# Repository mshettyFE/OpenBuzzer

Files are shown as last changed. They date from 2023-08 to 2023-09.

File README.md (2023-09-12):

An ESP8266-based quizbowl buzzer system.

# Downloading Code and Setting up Environment

An important note: I developed this on a Windows machine using WSL. I have no reason to believe that this code won't work across platforms, but your mileage may vary.

You first need to download VSCode and get the PlatformIO extension.

VSCode can be downloaded from [here](https://code.visualstudio.com/), while the PlatformIO instructions can be found [here](https://platformio.org/install/ide?install=vscode). The [quick start guide](https://docs.platformio.org/en/latest/integration/ide/vscode.html#quick-start) will give you an idea of the basic functionality of the extension.

You will also need the C/C++ Extension Pack (Can search and install with extension manager )

Once the above development tools are installed, open up a terminal and download the repository with the command

```
git clone https://github.com/mshettyFE/OpenBuzzer.git
```

NOTE: for Windows with WSL, you need to open up a WSL terminal instead of a typical powershell windows terminal.

cd into downloaded repository, then fire up VSCode with ```code .``` and click on the PlatformIO icon on the left hand taskbar. Choose the "Pick a Folder" option and select the root folder of the git repo you just downloaded. Wait for all the configurations to get setup.

# Uploading Code to Units

In general, you need to do the following steps:

1. Copy over a .cpp file in the [scripts](/scripts/) directory into [main.cpp](/src/main.cpp).
2. Plug in the ESP8266 NODEMCU dev board to a USB port
   * Aside: If you are using WSL, you need to passthrough the USB connection from Windows to WSL. See [here](https://learn.microsoft.com/en-us/windows/wsl/connect-usb) for instructions on how to do so.
3. Navigate to the PlatformIO icon in the taskbar, then select "Upload". It should just work.

For client machines (ie. each individual buzzer), copy over [Client.cpp](/scripts/ClientSide/Client.cpp) to main.

## Uploading filesystem (Server only)

For the main control unit (ie. server), you also need to flash the filesystem image prior to uploading the code. Follow steps 1-2 above, then under the PlatformIO tab, select ```Build Filesystem Image```. Afterwards, select ```Upload Filesystem Image```.

Once that is done, you can copy over [Server.cpp](/scripts/ServerSide/Server.cpp) to main and upload like normal.

# Ordering PCBs

The gerber files needed to create the PCBs are located at [here](/design/PCBs/Gerber). These specific design files work for [JLCPCB](https://jlcpcb.com/). Just drag and drop the zip files and order however many you want (Suggested is 5 Server boards and 15 client boards).

If you are ordering from a different manufacturer, or some of your component footprints are egregiously misaligned with the board (the NODEMCU form factor and RJ45 PCB mounts are not particularly well standardized), you can directly modify the design files located [here](/design/PCBs/KiCad/). 

A suggestion to see if the current design works for you PRIOR to ordering from a fabricating service: print out the PCB layout on printer paper and see if your components roughly line up. It's OK if the pins don't line up exactly, since they can be slightly bent with pliers to correctly mate with the drill holes.

# Assembly Tips

* Keep the soldering iron as low as feasible (Try not to go above 350 F). Lower heat means you are less likely to damage components and your tip
* Remember to properly clean the iron before and after use, and re-tin whenever you aren't using the iron
* Be careful not to smear solder onto the PCB traces while soldering. Pain to clean up
* The top left corner of the PCB (ie corner near OLED display) should align with the little divet on the bottom part of the enclosure
* OLED contacts go into indentation in OLED holder
* You can get away with 3 screws to secure the OLED, the PCB, and the cover 
* Make sure that there are no shorts between wires prior to hot gluing them in place (pain to remove)

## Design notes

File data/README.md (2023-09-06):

Here are website files.

* game_index.html: html skeleton
  * Rows get added to Ranking tbody as players buzz in
  * When Rescan gets pressed, Alive tbody gets populated with the current players connected
  * When Clear gets pressed, both Rranking and Alive are cleared, and all buzzers are reset to unlocked
* index.css: Bare bones css file
* Requests.jss: Opens up a WebSocket between client (say, a mobile device) and ESP8266 server. Reads JSON response from server and updates display accordingly. Also plays A4 for 1 second when someone first buzzes in
* A41Sec.mp3: tone that plays when player buzzes in

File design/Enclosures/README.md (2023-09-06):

Contains design files to 3D print enclosures.

* ```Fusion360``` contains .f3d files.
  * ButtonHoleChecker was a test print to see what size hole and threading worked for the buttons
  * OLEDHolder was a test print to pin down the hole placement that works for **MOST** displays. They might not align perfectly, but you should be able to drive in the screws.
  * BuzzerBot is where the PCB gets mounted. It is shared between the client and the server enclosures
  * BuzzerClientTop and BuzzerServerTop cover the PCB and provide access ports

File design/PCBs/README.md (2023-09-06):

PCB design files

* Gerber contains the files that get send to a fab lab. These files are for JLCPCB
* KiCad contains the KiCad projects for both all Clients and Server

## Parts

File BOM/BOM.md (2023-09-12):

# BOM (Bill of Materials)
Cost breakdown of each component and potential sources of each material. Excludes shipping and taxes. No affiliated links.

| Part | Cost | Minimum Count | Link |
| -----| ----- | ----| -----|
| ESP8266 NODEMCU| $0.99 | 2 (1 for server, 1 per client)| https://www.aliexpress.us/item/3256805522032182.html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|
|
| RS485 Modules | $0.30 | (1 for server, 1 per client) | https://www.aliexpress.us/item/3256801435484195.html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| 
| USB-C Breakout Board with Pins| $ 0.17 |  1 for the server | https://www.aliexpress.us/item/3256804935738941.html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|
RJ45 Ethernet PCB Mount | $1.73 per 10 | (1 for server, 1 per client) | https://www.aliexpress.us/item/2251832663908888.html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|
OLED Display | $1.21 | (1 for server, 1 per client) | https://www.aliexpress.us/item/2251832644208699.html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|
7 mm Momentary Push Button, Normally Open (NO) | $3.59 for 10 | (1 for server, 1 per client) | https://www.aliexpress.us/item/2251832768448275.html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 |
M2 x 4mm Self tapping  Phillip Head screws | $0.80 for 100 | In Theory, 12 per unit. You can use 9 though| https://www.aliexpress.us/item/3256804788361012.html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 |
3D Printing filament | For PLA, cheapest is around $20 dollars per kg | Each unit takes around 150 g, so around $3.00 per unit | https://www.amazon.com/XYZprinting-RFPLCXUS0CH-Vinci-Filament-Pearl/dp/B0142FW8W6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 |
22 awg solid core wire | $8.29 for 5 rolls of 40m 22 awg | around 40 cm per unit ($0.05) | https://www.aliexpress.us/item/2251832718635676.html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|
Solder | $1.00 for 50 g | Depends on how good of a soldering job you do | https://www.aliexpress.us/item/3256805017664990.html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|

You will need access to a 3D printer to create the enclosures.

With regards to the PCB, you will need some additional tools:

* a soldering iron
  * Since you will be making a lot of solder joints, get a quality soldering iron (preferably one with electronic temperature control)
* wire strippers
* snips
* electronics pliers
* brass wire sponge: to clean the tip

Some tools that are useful to have (but not strictly necessary):

* Helping hands (the tool. Although having friend hold some wires while you solder also works)
* A hot glue gun: used to cover up exposed leads from stripped wires and prevent shorts
* Solder suction gun: Good for when you screw up a solder joint
* Multimeter: Used to test for inadvertent short between traces

The cost per unit (excluding tax and shipping) comes out to:

* $6.40 for the server
* $6.23 for the client

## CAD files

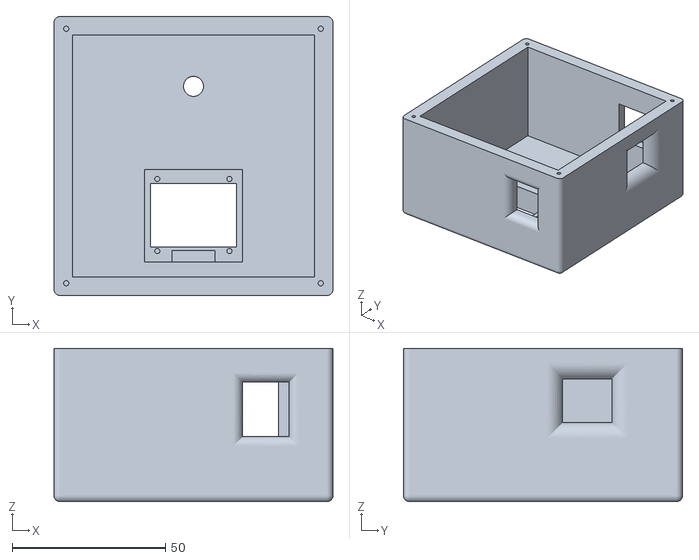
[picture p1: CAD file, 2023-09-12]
design/Enclosures/STL/BuzzerServerTop.stl
90.9 x 90.9 x 50.0

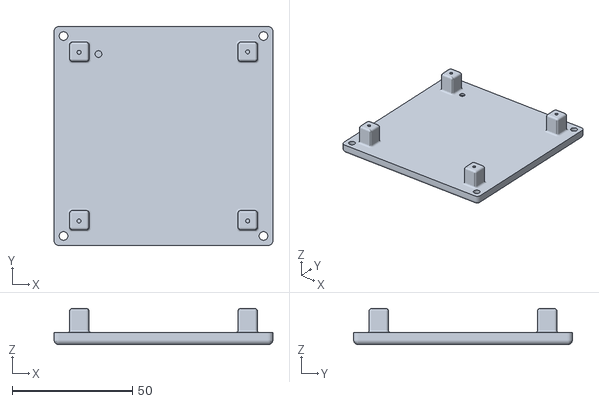
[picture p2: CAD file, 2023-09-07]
design/Enclosures/STL/BuzzerBot.stl
90.9 x 90.9 x 15.0

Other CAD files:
design/Enclosures/STL/BuzzerClientTop.stl
design/Enclosures/Fusion360/ButtonHoleChecker.f3d
design/Enclosures/Fusion360/BuzzerBot.f3d
design/Enclosures/Fusion360/BuzzerClientTop.f3d
design/Enclosures/Fusion360/BuzzerServerTop.f3d
design/Enclosures/Fusion360/OLEDHolder.f3d

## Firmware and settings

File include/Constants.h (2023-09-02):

#ifndef CONSTANTS
#define CONSTANTS

#include <ESP8266WiFi.h>
#include <ESPAsyncTCP.h>
#include <ESPAsyncWebServer.h>
#include <stdint.h>

const bool debug = false;
const bool v_debug = false;

const uint8_t SCREEN_WIDTH  = 128; // OLED display width, in pixels
const uint8_t SCREEN_HEIGHT =  64; // OLED display height, in pixels

// Possible actions to update web interface. WEB_UPDATE only send out by server
// WEB_CLEAR, WEB_RESCAN initiated by client

enum WebpageMessageTypes {WEB_INVALID,WEB_UPDATE,WEB_CLEAR,WEB_RESCAN,WEB_NOTHING};

const IPAddress local_IP(192,168,4,22);
const IPAddress gateway(192,168,4,9);
const IPAddress subnet(255,255,255,0);

// Possible Messages that can be sent. 
// ALIVE is used to register a device.
// TIMING is used to get current buzz-in time of device
// LOCK_IN is used to set a client as buzzed in
// RESET is used to clear state of devices

enum MessageType {INVALID=0,ALIVE=1,TIMING=2,LOCK_IN=3, RESET=4};

enum SenderType {SERVER=1, CLIENT=2};

const int8_t INVALID_DEVICE = 0;
const int8_t ALL_DEVICES = -1;

// ENABLE_PIN to toggle between transmit and receive
const uint8_t ENABLE_PIN = 2;

// TRIGGER_PIN to state if button has been pushed
const uint8_t TRIGGER_PIN = 14;

// I2S DAC pins
const uint8_t LRCLK_PIN= 12;
const uint8_t BCLK_PIN= 13;
const uint8_t DIN_PIN= 0;

// Maximum number of devices that can be connected
const uint8_t MAX_DEVICES = 10;

// Testing response wait time in microseconds.
const uint64_t WAIT_TIME = 100000;
// SendAll wait time in microseconds
const uint64_t SEND_ALL_WAIT_TIME = 500000;
// Webserver client refresh time
const uint64_t refresh_client_pool = 1000000;

// Start and end characters for messages
const char start_marker = '!';
const char end_marker = '@';
// Delimiter to seperate different values within a message
const char delimiter[2] = "#";

// size of buffer for both client and server (messages shouldn't exceed 32 bits)
const uint8_t bufferSize = 32;

typedef struct Record {
	int8_t	device_id;
	uint64_t	timing;
} Rec;

extern WebpageMessageTypes current_webpage_update;

#endif

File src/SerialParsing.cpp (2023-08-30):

#include "SerialParsing.h"
#include "Constants.h"

#include <errno.h>
#include <Arduino.h>
#include <stdint.h>

bool SetInvalidServer(int8_t device_id, MessageType& msgt,uint64_t& timing){
    msgt = INVALID;
    device_id = 0;
    timing = 0;
    return false;
}

bool SetInvalidClient(int8_t device_id, MessageType& msgt){
    msgt = INVALID;
    device_id = 0;
    return false;
}

void ReceiveChar(char* buffer, uint8_t& buffer_index, bool& msg_start,bool& msg_end){
// read in a single character from the bus if available
  char rc;
  while(Serial.available() > 0 ){
    rc = Serial.read();
//    Serial.printf("%c",rc);
    if(!msg_start){
          if(rc==start_marker){
//            Serial.println("start");
            // Point to beginning of array, and allow future reads of Serial to be processed
            buffer_index = 0;
            msg_start = true;
          }
    }
    else{
      if(rc!=end_marker){
// read in characters, then advance index
//            Serial.println("mid");
        buffer[buffer_index] = rc;
        buffer_index++;
// If the index exceeds the buffer size,t then we have gone on for too long. set msg_start and msg_end to false, reset buffer to start and return
        if(buffer_index>=bufferSize){
          msg_start = false;
          msg_end = false;
          buffer_index = 0;
          return;
        }
      }
      else{
// We are at the end of the message. Need to null terminate string
//            Serial.println("end");
        buffer[buffer_index] = '\0';
        msg_end = true;
// exit to start parsing message
        return ;
      }
    }
  }
}

bool ParseMsgServer(char* buffer, int8_t& device_id, MessageType& MSGT, uint64_t& timing){
// Assumes message has one of two forms:
// !%d#%d#%d@ where the first %d is sender_id, second %d is device ID and   third %d is the message type 
// !%d#%d#%d#%llu@ where the first %d is sender_id, second %d is device ID, and  third %d is the message type and %llu is a time

// Check Sender ID
  if(debug){
    Serial.printf("\nClient");
    Serial.println(buffer);
    Serial.printf("\n");
  }
  char* endIndex = strtok(buffer,delimiter);
  if(endIndex==NULL){
    return SetInvalidServer(device_id,MSGT,timing);
  }
  int sender_id = atoi(endIndex);
  if(sender_id!=CLIENT){
    return SetInvalidServer(device_id,MSGT,timing);
  }
// Check Device ID
  endIndex = strtok(NULL,delimiter);
// invalid message rest of message irrelevant
  if(endIndex==NULL){
    return SetInvalidServer(device_id,MSGT,timing);
  }
  device_id = atoi(endIndex);
  if((device_id<1 || device_id>MAX_DEVICES)){
    return SetInvalidServer(device_id,MSGT,timing);
  }
// Parse message type. For ALIVE and TIMING, check for additional timing info
  endIndex = strtok(NULL,delimiter);
// invalid message rest of message irrelevant
  if(endIndex==NULL){
    return SetInvalidServer(device_id,MSGT,timing);
  }
  int temp = atoi(endIndex); 
// invalid message type
  if(temp<ALIVE || temp>RESET){
    return SetInvalidServer(device_id,MSGT,timing);
  }
  else{
    switch(temp){
      case ALIVE:
        MSGT = ALIVE;
        // Grab next part
        endIndex = strtok(NULL, delimiter);
        if(endIndex==NULL){
          return SetInvalidServer(device_id,MSGT,timing);
        }
        timing = strtoul(endIndex,NULL,10);
        if(errno){
          return SetInvalidServer(device_id,MSGT,timing);
        }
        break;
      case TIMING:
        MSGT = TIMING;
        // Grab next part
        endIndex = strtok(NULL, delimiter);
        if(endIndex==NULL){
          return SetInvalidServer(device_id,MSGT,timing);
        }
        timing = strtoul(endIndex,NULL,10);
        if(errno){
          return SetInvalidServer(device_id,MSGT,timing);
        }
        break;
      case LOCK_IN:
          MSGT = LOCK_IN;
          break;
      case RESET:
          MSGT = RESET;
          break;
      case INVALID:
     default:
        return SetInvalidServer(device_id,MSGT,timing);
   }
  }
  return true;
}

bool ParseMsgClient(char* buffer, int8_t& device_id, MessageType& MSGT){
// Assumes message has the following form:
// !%d#%d#%d@ where the first %d is either SERVER or CLIENT, the second %d is the device_id and third %d is message type
  if(debug){
    Serial.printf("\nServer");
    Serial.println(buffer);
    Serial.printf("\n");
  }
// Check if first character is from SERVER
  char* endIndex = strtok(buffer,delimiter);
// If we read nothing, return invalid message
  if(endIndex==NULL){
    return SetInvalidClient(device_id,MSGT);
  }
  int sender_id = atoi(endIndex);
  if(sender_id!=SERVER){
    return false;
  }

// Check device ID
  endIndex = strtok(NULL,delimiter);
// If we read nothing, return invalid message
  if(endIndex==NULL){
    return SetInvalidClient(device_id,MSGT);
  }
// check if device_id is valid
  device_id = atoi(endIndex);
// continue if device_id is all devices
  if(device_id==ALL_DEVICES){
    ;
  }
// Since the device_id is not all devices, this means that the device id should be inclusively bounded between 1 and MAX_DEVICES
  else if( device_id<1 || device_id > MAX_DEVICES){
    return SetInvalidClient(device_id,MSGT);
  }

// Grab next part
  endIndex = strtok(NULL, delimiter);
  if(endIndex==NULL){
    return SetInvalidClient(device_id,MSGT);
  }

// This should be the MessageType. Since the enum is contiguous, we can check if atoi() returns something below or above valid range of enum
  int temp = atoi(endIndex);
// invalid message type
  if(temp<ALIVE || temp>RESET){
    return SetInvalidClient(device_id,MSGT);
  }
  else{
    switch(temp){
      case ALIVE:
        MSGT = ALIVE;
        break;
      case RESET:
        MSGT = RESET;
        break;
      case TIMING:
        MSGT = TIMING;
        break;
      case LOCK_IN:
        MSGT = LOCK_IN;
        break;
      case INVALID:
      default:
        return SetInvalidClient(device_id,MSGT);
    }
  }
  return true;
}

void SendMsgServer(int8_t Device_ID, MessageType msgt){
// turn on transmission
  if(debug){
    Serial.printf("Send:%d,%d\n",Device_ID,msgt);
  }
    digitalWrite(ENABLE_PIN,HIGH);
    Serial.printf("!%d#%d#%d@",SERVER,Device_ID,msgt);
// Make sure data is written to bus. Currently is blocking, so can't reset in while server is sending. Shouldn't be a problem though?
  Serial.flush();
// turn on receiving
    digitalWrite(ENABLE_PIN,LOW);
}

void SendMsgClient(int8_t Device_ID, MessageType msgt, uint64_t timing){
// If the Device_ID is below 0 (ie INVALID or a SEND_ALL message), then do nothing
  if(Device_ID<=0){
    return;
  }
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

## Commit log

2023-08-22 Got I2C Working
2023-08-24 Fixed RS485Test Code by adding start and end characters
    [Client.cpp, RS485TestClient.cpp, RS485TestServer.cpp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]
2023-08-26 Got multiple boards communicating with server
2023-08-26 Added RESET. Works for multiple clients. Also tested out more stringent wait times
    [Client.cpp, Constants.h, SerialParsing.cpp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]
2023-08-26 Revamped ALIVE message. Now poll current time of each client and save to server. Will use this time to syncrhonize the buzzin times.
    [Client.cpp, Constants.h, SerialParsing.cpp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]
2023-08-26 Fixed but with RESET. Needed to wait for client to respond to RESET message. Otherwise, Server moved on too quickly
    [Client.cpp, Constants.h, Server.cpp]
2023-08-28 I think I fixed the bug where clients were able to communicate with each other and send invalid messages. I found this out when LOCK_IN messages kept being sent to some cients, even if the server was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
    [Client.cpp, Constants.h, SerialParsing.cpp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]
2023-08-29 I think I fixed the LOCK_IN bug. As it stands, this is a functional system now. Still need to tweak a couple things. On the software side, I need to add sound, tweak waiting times, get web interface 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
    [Client.cpp, Constants.h, SerialParsing.cpp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]
2023-08-30 Checked device_id from uint8_t to int8_t universally in preparation for send all messages
2023-08-30 Added SEND_ALL capability. Only really useful when send with RESET though
    [Client.cpp, Constants.h, SerialParsing.cpp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]
2023-09-01 Got Audio working. Need to update PCBs and enclosure to reflect that audio is no longer part of buzzer Hardware.
    [Server.cpp]
2023-09-02 Fiddled with WAIT_TIME. Turns out, you can't daisy chain more that 6 or so in a row. You need to use both ports on Server board. Either that, or redesign each board to include a boost converter.
    [Constants.h, Server.cpp]
2023-09-03 Added design files
    [BuzzerBottom.f3d, BuzzerClientTop.f3d, BuzzerServerTop.f3d]
2023-09-03 Fixed Server PCB
2023-09-03 Cleaned up design files. Added Gerber and stl files for default version
    [OpenBuzzerBottom.stl, OpenBuzzerClientTop.stl, OpenBuzzerServerTop.stl]
2023-09-04 Removed old enclosure files
    [BuzzerBottom.f3d, BuzzerClientTop.f3d, BuzzerServerTop.f3d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]
2023-09-04 Re organized design files and corrected enclosure files. Added test prints for button threading and OLED holder
    [ButtonHoleChecker.f3d, BuzzerBot.f3d, BuzzerBot.stl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]
2023-09-06 Added documentation on downloading repo, uploading code, and ordering PCBs
2023-09-06 Forgot to model threads in enclosure
    [BuzzerClientTop.stl, BuzzerServerTop.f3d, BuzzerServerTop.stl]
2023-09-07 Modified Bottom part of enclosure so that PCB isn't off center. Modified enclosure tops so that **hopefully** it is easier to remove connectors
    [BuzzerBot.f3d, BuzzerBot.stl, BuzzerClientTop.f3d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]
2023-09-07 Modified OLED holder in Enclosures
    [BuzzerClientTop.f3d, BuzzerClientTop.stl, BuzzerServerTop.f3d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]
2023-09-12 Added some padding to OLED Holder on Lids
    [BuzzerClientTop.f3d, BuzzerClientTop.stl, BuzzerServerTop.f3d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]
